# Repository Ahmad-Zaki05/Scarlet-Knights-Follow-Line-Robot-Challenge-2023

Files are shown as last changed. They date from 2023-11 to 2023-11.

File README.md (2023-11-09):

# Scarlet-Knights-Follow-Line-Robot-Challenge-2023
This repository is made to showcase the work done by my students and myself in order to compete in the Follow Line category in Robot Challenge Egypt 2023 and winning 2nd place.

Photos of the robot and team members as well as videos of the practice and competition trials can be seen here: https://drive.google.com/drive/folders/1q-2HFmgtx5S_9SZfV8urcmPSkT2x9SGe

The team's members are:
  - Yahia Osama, works as the mechanical designer
  - Galal Eldin Ahmed, works as the electrical and PCB designer
  - Yahia Amr, works as the programmer
  - Ahmad Zaki, the coach

The robot's components are:
  - 5 * TCRT5000 IR sensors: https://makerselectronics.com/product/infrared-line-follower-sensor
  - 2 * 620 RPM motors: https://ampere-electronics.com/product/25ga370-dc-gear-motor-12v-620rpm/
  - 1 * Arduino Nano: https://makerselectronics.com/product/arduino-nano-with-ch340-uploader-micro-usb
  - 1 * Cytron Dual Channel: https://store.fut-electronics.com/products/dual-channel-dc-motor-driver-10a-each?_pos=2&_sid=8398b2827&_ss=r
  - 2 * motor holders

Explanations for the mechanical parts and PCB are in the description of each file.

The code is based on a bang-bang control scheme. We opted for this method as it is easier to test and is less time-consuming, unlike other methods, such as PID, that need a lot of time to reach the optimal kp, kd and ki values. We tried solving the main issue with the bang-bang method, which is the oscillations that occur due to the rapid changing of states, by putting the inner IR sensors at a close distance and implemented two while loops, one for the right turn and one for the left, to always make the robot return to the neutral position. The close distance and the tested speeds made the oscillations very small that it sometimes did not even occur. When the outer sensors read black, the robot has to make a sharp turn until it returns to the neutral position. The two functions whileright and whileleft were implemented in order to quickly change from a sharp right turn to a sharp left turn or vice versa in sharp consecutive corners.

This is all that we have been able to make during the three months we have been working for and we hope that we will use this year's experience in order to make a much better robot next year and win first place in RC 2024 in Inshaa'Allah.

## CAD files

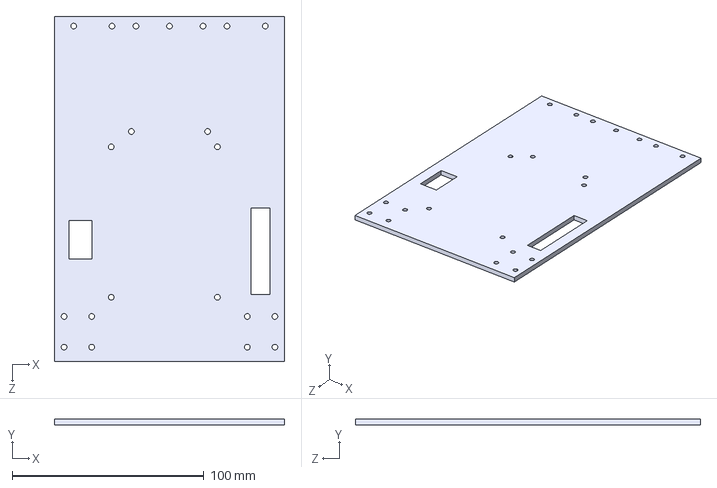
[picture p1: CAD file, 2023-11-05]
Mechanical Parts/Main Body.STEP
120.0 x 3.00 x 180.0 mm

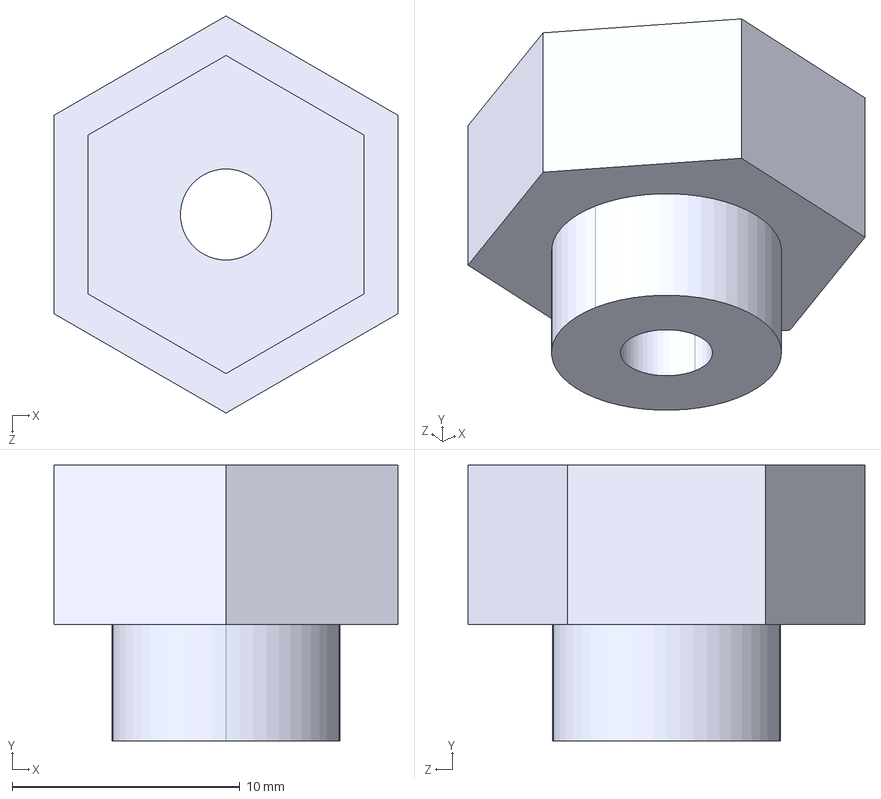
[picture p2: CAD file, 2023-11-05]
Mechanical Parts/Coupler Holder.STEP
15.1 x 12.1 x 17.4 mm

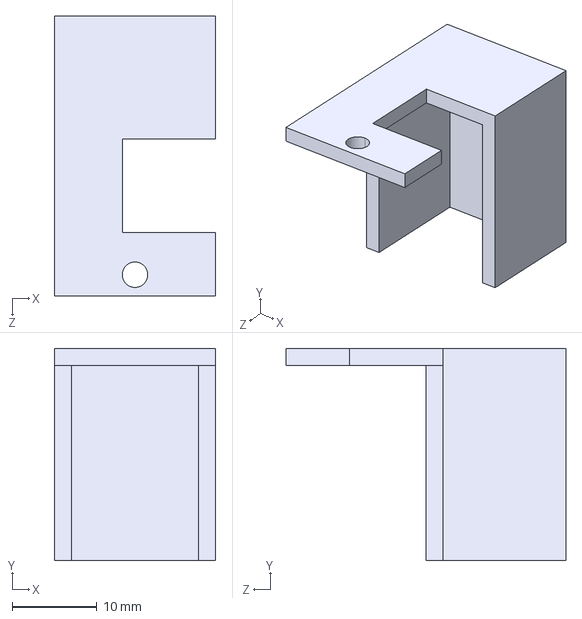
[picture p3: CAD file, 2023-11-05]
Mechanical Parts/IR Sensors Cover.STEP
19.0 x 25.0 x 33.0 mm

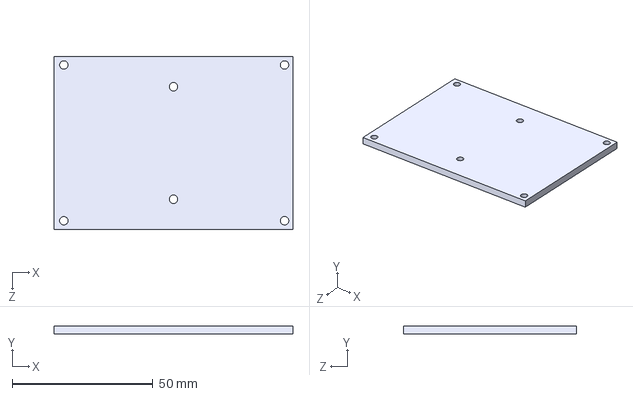
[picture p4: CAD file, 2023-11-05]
Mechanical Parts/Battery Holder Platform.STEP
85.0 x 3.00 x 61.5 mm

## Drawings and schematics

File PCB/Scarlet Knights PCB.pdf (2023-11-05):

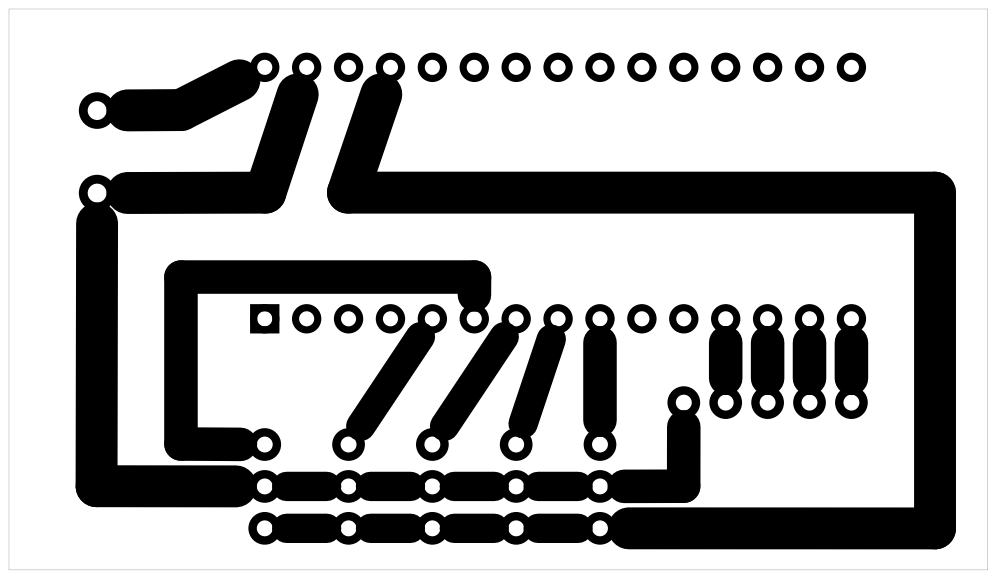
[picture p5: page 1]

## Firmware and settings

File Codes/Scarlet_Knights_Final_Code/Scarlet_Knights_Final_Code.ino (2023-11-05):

//sensors
#define LSP2 6
#define LSP 5
#define MSP 4
#define RSP 2
#define RSP2 3
//motor
#define LD 12
#define RD 10
#define LS 11
#define RS 9
//other
#define SPD 150               //FOWARD
#define SPD2 250              //MAIN WHEEL SPEED
 #define SPD3 92              //SECONDARY WHEEL SPEED
#define SPD4 200              //main wheel for while loops
#define SPD5 50               //secondary wheel for while loops
#define MOTOR_DIRECTION HIGH  //SECONDARY WHEEL DIRECTION
#define MOTOR_DIRECTION2 LOW  //SECONDRY wheel dircetion for while loops
//variables
int LL, L, M, R, RR;

void setup() {
  pinMode(LSP2,INPUT);
  pinMode(LSP, INPUT);
  pinMode(MSP, INPUT);
  pinMode(RSP, INPUT);
  pinMode(RSP2, INPUT);
  pinMode(LD, OUTPUT);
  pinMode(RD, OUTPUT);
  pinMode(LS, OUTPUT);
  pinMode(RS, OUTPUT);
  // Serial.begin(9600);
}

void loop() {
  LL = digitalRead(LSP2);
  L = digitalRead(LSP);
  M = digitalRead(MSP);
  R = digitalRead(RSP);
  RR = digitalRead(RSP2);
  // Serial.print(LL);
  // Serial.print("\t");
  // Serial.print(L);
  // Serial.print("\t");
  // Serial.print(M);
  // Serial.print("\t");
  // Serial.print(R);
  // Serial.print("\t");
  // Serial.println(RR);

  //conditions
  if (LL == 1 && RR == 0) {
    if (M == 1 && L == 1 && R == 1) {
      digitalWrite(LD, MOTOR_DIRECTION2);
      digitalWrite(RD, HIGH);
      analogWrite(LS, SPD5);
      analogWrite(RS, SPD4);
      //Serial.print(LL);
      // Serial.print("\t");
      // Serial.print(L);
      // Serial.print("\t");
      // Serial.print(M);
      // Serial.print("\t");
      // Serial.print(R);
      // Serial.print("\t");
      // Serial.println(RR);
    } else {
      whileleft();
    }
  }

  else if (LL == 0 && RR == 1) {
    if (M == 1 && L == 1 && R == 1) {
      digitalWrite(LD, HIGH);
      digitalWrite(RD, MOTOR_DIRECTION2);
      analogWrite(LS, SPD4);
      analogWrite(RS, SPD5);
      Serial.print(LL);
      // Serial.print("\t");
      // Serial.print(L);
      // Serial.print("\t");
      // Serial.print(M);
      // Serial.print("\t");
      // Serial.print(R);
      // Serial.print("\t");
      // Serial.println(RR);
    } else {
      whileright();
    }
  }

  //right
  else if (R == 1 && L == 0) {
    while (M == 0 && LL == 0 && RR==0) {
      digitalWrite(LD, HIGH);
      digitalWrite(RD, MOTOR_DIRECTION);
      analogWrite(LS, SPD2);
      analogWrite(RS, SPD3);
      LL = digitalRead(LSP2);
      M = digitalRead(MSP);
      RR = digitalRead(RSP2);
    }
  }

  //left
  else if (R == 0 && L == 1) {
    while(M==0 && RR==0 && LL==0){
    digitalWrite(LD, MOTOR_DIRECTION);
    digitalWrite(RD, HIGH);
    analogWrite(LS, SPD3);
    analogWrite(RS, SPD2);
    M = digitalRead(MSP);
    LL = digitalRead(LSP2);
    RR = digitalRead(RSP2);}

  }
  //forward
  else {
    //previous_time=millis();
    //if(min2<set_speed<max2){set_speed=set_speed + 15}
    digitalWrite(LD, HIGH);
    digitalWrite(RD, HIGH);
    analogWrite(LS, SPD);
    analogWrite(RS, SPD);
  }
}
void whileright() {
  while (M == 0 && L == 0 && R==0) {
    digitalWrite(LD, HIGH);
    digitalWrite(RD, MOTOR_DIRECTION2);
    analogWrite(LS, SPD4);
    analogWrite(RS, SPD5);
    M = digitalRead(MSP);
    R = digitalRead(RSP);
    L = digitalRead(LSP);
    LL = digitalRead(LSP2);
    if (LL == 1) {
      whileleft();
      return;
    }
  }
}
void whileleft() {
  while (M == 0 && R == 0 && L==0) {
    digitalWrite(LD, MOTOR_DIRECTION2);
    digitalWrite(RD, HIGH);
    analogWrite(LS, SPD5);
    analogWrite(RS, SPD4);
    M = digitalRead(MSP);
    L = digitalRead(LSP);
    R = digitalRead(RSP);
    RR = digitalRead(RSP2);
    if (RR == 1) {
      whileright();
      return;
    }
  }
}

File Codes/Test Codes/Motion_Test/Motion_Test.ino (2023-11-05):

// This code was written by Yahia Amr and his coach Ahmad Zaki
// This code is for testing the motion of the robot by testing the directions and the speeds of each motor
#define leftSpeed 11
#define rightSpeed 9
#define leftDirection 12
#define rightDirection 10
int dt = 1750;
int speed1 = 254;
int speed2 = 254 ;
int dt2 = 4000;


void setup() {
  pinMode(leftSpeed, OUTPUT);
  pinMode(leftDirection, OUTPUT);
  pinMode(rightSpeed, OUTPUT);
  pinMode(rightDirection, OUTPUT);
  Serial.begin(9600);
}

void loop() {

  // forward
  digitalWrite(leftDirection , HIGH);
  digitalWrite(rightDirection , HIGH);
  analogWrite(leftSpeed , speed1);
  analogWrite(rightSpeed , speed1);
  delay(dt);

  // left wide
  digitalWrite(leftDirection , LOW );
  digitalWrite(rightDirection , HIGH );
  analogWrite(leftSpeed , 0 );
  analogWrite(rightSpeed , speed1);
  delay(dt);

  // left tight
  digitalWrite(leftDirection , LOW );
  digitalWrite(rightDirection , HIGH );
  analogWrite(leftSpeed , speed1);
  analogWrite(rightSpeed , speed2);
  delay(dt);

  // right wide
  digitalWrite(leftDirection , HIGH);
  digitalWrite(rightDirection , LOW);
  analogWrite(leftSpeed , speed1 );
  analogWrite(rightSpeed , 0  );
  delay(dt);

  // right tight
  digitalWrite(leftDirection , HIGH);
  digitalWrite(rightDirection , LOW);
  analogWrite(leftSpeed , speed2);
  analogWrite(rightSpeed , speed1);
  delay(dt);

  //backwards
  digitalWrite(leftDirection , LOW);
  digitalWrite(rightDirection , LOW);
  analogWrite(leftSpeed , speed1);
  analogWrite(rightSpeed , speed1);
  delay(dt);
  
  // stop
  digitalWrite(leftDirection , HIGH);
  digitalWrite(rightDirection , HIGH);
  analogWrite(leftSpeed , 0);
  analogWrite(rightSpeed , 0);

  delay(5000);
}

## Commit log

2023-11-05 A platform to put the battery holder on
    Due to the robot's body's dimensions, we had to make another platform to put the battery holder as it wouldn't fit without changing the dimensions, which would worsen the robot's performance as prove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
    [Battery Holder Platform.STEP]
2023-11-05 The robot's main body
    This is the main body of the robot on which all the components are fixed. This is the best version that we have reached.
    [Main Body.STEP]
2023-11-05 3D Printed Covers for the IR sensors
    A problem that we faced was that the IR sensor's calibration would change in different lighting conditions. This cover was made to surround the transmitter and receiver of the sensor to prevent the changes in calibration.
    [IR Sensors Cover.STEP]
2023-11-05 3D printed part that joins the coupler with the wheels
    This part was made to solve the issue of tilted wheels as the tilted wheels had much less contact surface area with the ground, thus decreasing friction between the wheels and the ground and affecting performance negatively. Unfortunately, this part didn't make the final cut due to poor printing quality
    [Coupler Holder.STEP]
2023-11-05 Create IR_Sensor_Testing.ino
    This code was used during calibration the of IR sensors.
2023-11-05 The final PCB design
    This is the final PCB. It is a custom PCB made on a software called Fritzing. We make our PCBs manually so we print these PDFs on glossy paper, then we iron it (like ironing clothes xD) on copper she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
2023-11-08 Final PCB Design
    This is the PCB design that we have managed to make as small as possible to occupy less space, thus making the robot smaller. The PCB is mainly an Arduino Nano shield and its purpose is to make the e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
    [Scarlet Knights Final PCB.fzz]
